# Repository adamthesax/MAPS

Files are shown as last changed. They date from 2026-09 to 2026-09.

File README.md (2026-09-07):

# M.A.P.S. — Modular Awesome Photonic System

**`mapscam`** is the camera-enclosure repository of the M.A.P.S. project: a **modular,
3D-printed enclosure system for board-level C-mount CMOS cameras**, for fixed and monitoring
installations. The housing is a short stack of independent printed modules — front (lens),
body, sensor carrier, rear (cabling) — on one shared mechanical interface, so each piece can
be reprinted or swapped as sensors and lenses change.

Parametric [OpenSCAD](https://openscad.org) source. Mechanical + docs only — no firmware.

> **Status: v0.1 scaffold.** The geometry renders, the flange-focal-distance math is
> enforced in code, and every variant passes `make check`. Nothing has been printed and
> fit-checked against hardware yet — treat dimensions as a starting point, not gospel.

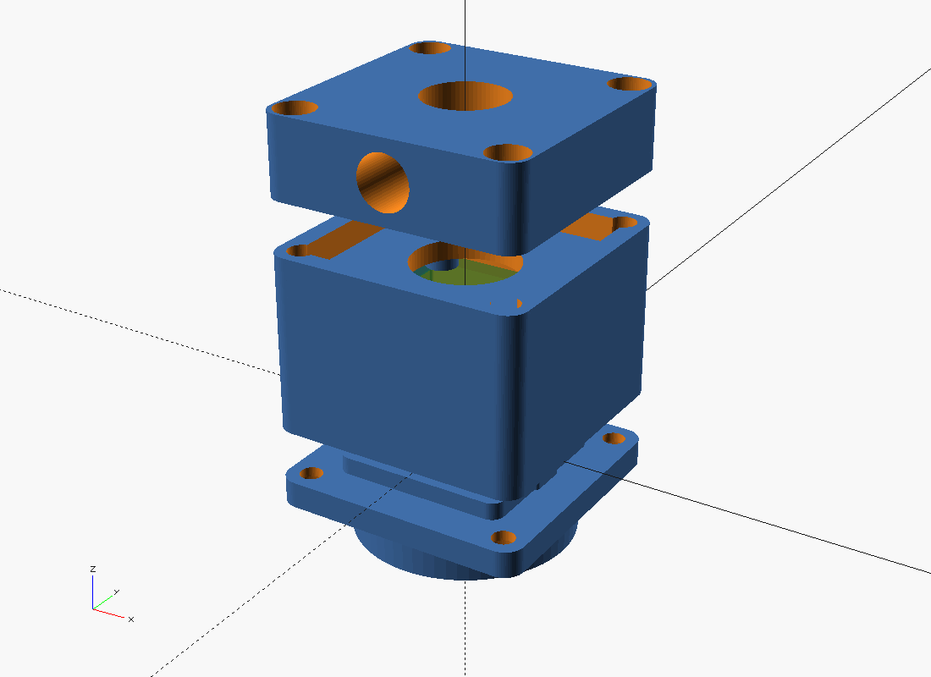
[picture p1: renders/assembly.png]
exploded assembly


## Quick start

```bash
git clone --recurse-submodules <this repo>
cd mapscam
brew install openscad          # or apt / your package manager
python3 --version              # 3.11+ (needed by tools/gen.py — stdlib only)
make check                     # regen check + render every component/part, fail on any warning
make                           # STLs + preview PNGs into stl/ and renders/
```

Render a single part:

```bash
OPENSCADPATH=vendor openscad -o stl/body.stl -D 'part="body"' scad/variants/generic_29mm_c.scad
```

Or open `scad/camera.scad` (or `scad/lens.scad`) in the OpenSCAD GUI and use the
**Customizer**.

## Components

Every buildable thing — a camera enclosure, a printed lens barrel — is one small TOML file
under [`components/`](components/). `tools/gen.py` (run by `make gen`, and automatically by
`make`) expands each into a `scad/variants/<name>.scad` stub plus the Make wiring. **The
TOML is the source of truth**; the `.scad` stubs and `components.json` are generated — do
not hand-edit them. See [docs/components.md](docs/components.md).

<!-- BEGIN GENERATED:components -->
### Camera components

| Variant | Description |
|---|---|
| `generic_29mm_c` | 29 mm board, C-mount, printed thread |
| `generic_29mm_c_ring` | 29 mm board, C-mount, captured metal ring |
| `generic_29mm_cs` | 29 mm board, CS-mount, printed thread |

### Lens components

| Variant | Description |
|---|---|
| `achromat_12mm_c` | Ø12.7 achromat barrel, C-mount, M30.5 filter |

### Receiver components

| Variant | Description |
|---|---|
| `vibrometer_80mm` | Ø80 f150 receiver, fixed focus, 808 nm filter, C-mount |
<!-- END GENERATED:components -->

Add your own: drop a TOML in `components/camera/` or `components/lens/`, run `make gen`,
then `make check`. See [docs/components.md](docs/components.md) and the `add-camera-variant`
/ `add-lens-body` skills.

## The idea in one table

| | C-mount | CS-mount |
|---|---|---|
| Thread | 1.000"-32 UN | 1.000"-32 UN |
| Flange focal distance (flange → sensor) | **17.526 mm** | **12.526 mm** |

`scad/lib/camera/params.scad` does **not** let you set the body length — it *solves* it from
that flange focal distance, your sensor's PCB-to-active-surface number, standoff height, and
a shim allowance, then `assert()`s the stack is physically possible. A printable shim set
(`part = "shims"`) takes up the ± tolerance for back focus.

## Print checklist (per camera)

`front` · `body` · `carrier` · `rear` · `shims` — plus `base` if wall-mounting.
Fasteners, inserts, gland: [docs/bom.md](docs/bom.md).
Material and orientation: [docs/print-settings.md](docs/print-settings.md).

## Repo layout

```
components/            SOURCE OF TRUTH — one TOML per component (+ _type/ defs)
tools/gen.py           expands components/*.toml -> variant stubs + build wiring
scad/
  camera.scad          Customizer entry point (camera type)
  lens.scad            Customizer entry point (lens type)
  lib/
    constants.scad     shared: C/CS optics, thread spec, fastener dims, filter + NATO rail
    util.scad  hardware.scad         shared helpers
    camera/            params · dispatch · interface · front_plate · body ·
                       sensor_carrier · rear_plate · base_mount · accessory_rail ·
                       shims · c_mount
    lens/              params · dispatch · barrel · retainer · hood
  variants/            GENERATED stubs (committed) — do not hand-edit
components.json         GENERATED manifest (committed)
docs/                  components, design notes, modularity, BOM, print, assembly, calibration
vendor/BOSL2/          threading & helpers (git submodule)
```

## Skills

`.claude/skills/` holds repo-specific [Claude Code](https://claude.com/claude-code) skills
for common jobs — adding a camera variant or a lens body, rendering/QC, print prep, tuning
back focus. See [.claude/skills/README.md](.claude/skills/README.md).

## Licence

OpenSCAD sources and tooling: **MIT** ([LICENSE](LICENSE)).
Docs and renders: **CC-BY-4.0** ([LICENSE-docs](LICENSE-docs)).
Vendored BOSL2: BSD-2-Clause (`vendor/BOSL2/LICENSE`).

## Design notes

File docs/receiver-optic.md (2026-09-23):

# Vibrometer receiver optic

A large-aperture receiver telescope for the M.A.P.S. laser vibrometer
(see [PR #1](https://github.com/adamthesax/MAPS/pull/1) for the vibrometer roadmap).
It is its own component **type** (`components/receiver/*.toml`, `scad/lib/receiver/`),
like `lens`, because none of the camera sensor stack applies.

```
  target <--[ Ø80 optic ]===== barrel =====(socket)[ neck + filter cell ][ 1"-32 ]-- camera -- detector
             f ≈ 150 mm    Ø90 tube, holds the optic   plugs in, 3 screws    thread  z = 0   (BPW34 + AFE)
                                                       808 nm filter lives here (all -Z of z=0)
```

The bought **Ø80 mm, f ≈ 150 mm** optic focuses the returned beam through a small
**8 mm 808 nm bandpass filter** onto the detector, which rides on a stock mapscam
camera.

## Camera interface — `mount`

**`mount = "C"` (default).** The `stem` ends in a **male 1"-32 thread** and screws
straight into a stock `generic_29mm_c` front plate (`lens_mount_style = "thread"`) —
the receiver is just a C-mount lens, no custom front plate. A Ø`shoulder_d` disc
gives a finger grip and backstops the thread. **Nothing of the receiver reaches past
the seating plane into the camera** — the bare thread is all that goes +Z, and the
whole filter cell sits at -Z inside the neck root (see below). So the receiver is a
clean C-mount citizen: it drops onto any C-mount camera, and mapscam body variants
can put anything they like right behind the front plate. It seats the same way a
mapscam printed C-mount lens does; the camera shim stack trims focus. A Ø90 barrel
on a printed 1"-32 thread is a long cantilever — plan on a barrel brace for anything
but short bench runs, and a dab of thread-locker or a set screw so it can't back off
under vibration.

**`mount = "flange"`.** The `stem` carries its own front plate — the same
rectangular register + 4-corner M3 pattern as a camera `front_plate` (a bare
`generic_29mm` body bolts straight on). Use this when you want the stiff bolted
joint or a keyed orientation. Set `body_outer_x` / `body_outer_y` to that body's
footprint. Same filter cell, same "nothing into the cavity" rule.

## Fixed focus

This is **one rigid tube**. The `stem` (camera interface + filter cell + a short neck)
plugs `join_len` into a socket in the rear of the `barrel` (holds the optic) and is
pinned with **3 radial screws** into a groove in the neck. `flange_to_optic`
(seating plane → optic rear face) is fixed at the design value; the camera shim stack
takes up the detector-position slack, same as a normal lens.

**Focus control is a later pass** — most likely by making the element position
inside the `barrel` adjustable (a threaded element cell), which is a small, cheap
part and keeps the load path out of any moving joint.

## Ø80 optic cell and lens retainer

The optic **loads from the front (muzzle) end** of the `barrel` and seats on a
shoulder machined into the bore (the step from `pocket_bore` down to `barrel_bore`
at `z = -element_edge_thk`). The `lens_retainer` then **threads into the barrel**
ahead of the optic and clamps it back against that seat — same scheme as the
`lens` component's `scad/lib/lens/retainer.scad`. It is a private printed pair, so it
goes through `print_thread()`: 2.5 mm pitch, 45° flanks, 0.55 mm diametral clearance on
the barrel side, and a 7.5 mm (3-turn) ring. See [printable-threads.md](printable-threads.md),
which uses this thread as its case study.

An earlier revision held the optic with 3 radial M3 set screws into a V-groove on
a plain ring, with the front aperture and the rear (trunk) bore both narrower than
the Ø80 element — the element could not physically pass through either end to
reach its own pocket. The threaded ring fixes this: the whole front bore, from the
muzzle through the retainer thread, stays wider than `element_d` until the seat
shoulder, so the optic drops straight in and only the last step narrows to hold it.

## Coordinate convention

Mirror of the camera: **`z = 0` is the seating plane** (the `"C"` shoulder, or the
`"flange"` front face) that meets the camera. Only the **bare thread** goes **+Z**
(then the camera's own detector); the **filter cell and the optics are all at −Z**,
out toward the target. `stem.scad` is authored in this frame; `barrel.scad` is
authored in its own frame (optic rear face at `z = 0`) and `dispatch.scad` places it
at `−flange_to_optic`.

## The stack (enforced in `scad/lib/receiver/params.scad`)

```
pocket_bore    = element_d + 2·element_fit             // Ø80 optic pocket
barrel_len     = flange_to_optic − stem_neck_len       // optic rear -> barrel rear face
cone_d(z)      = clear_aperture_d · |z| / flange_to_optic   // the light cone behind the optic
neck_bore      = ceil(cone_d(−stem_neck_len − join_len) + 4) // must clear the cone at the joint
neck_od        = neck_bore + 2·wall
socket_bore    = neck_od + 2·join_fit
socket_od      = socket_bore + 2·wall
taper_len      = max(14, (barrel_od − socket_od) / 2)  // OD→socket blend, ≤45° from vertical
```

`taper_len` is set from the radial drop, not fixed, so the barrel's OD→socket cone
is never steeper than 45° from vertical. The barrel prints **optic-end-down**; that
cone's inner face leans in over the main bore as it rises, and ≤45° keeps it
support-free. Bigger optic → bigger drop → longer blend, automatically.

Why the barrel is most of the tube: the f/1.9 cone is still ~Ø45 only 60 mm behind
the optic, so any tube back there has to be wide. The Ø90 barrel bore carries it
until the cone has shrunk to ~Ø18, ~`stem_neck_len` from the flange — that is where
the narrow `stem` neck takes over. Push `stem_neck_len` up and `neck_bore` grows
with it (asserted); push it down and the neck gets stubby.

`assert()`s fail the render if: the clear aperture leaves no seat rim; a wall
(barrel / stem / socket) is under `wall`; the lens retainer thread + wall don't
fit the barrel; the neck bore vignettes the cone at the joint; the filter
retainer thread + wall don't fit the stem neck; the filter cell runs into the
stem↔barrel joint; `thread_bore_d` leaves too little wall on the male thread;
or `flange_to_optic` is too short for the barrel.

## Parts (`make vibrometer_80mm`)

| Part | Prints | Notes |
|---|---|---|
| `stem` | 1 | camera interface (`"C"` male 1"-32 + grip shoulder, or `"flange"` register) + filter cell in the neck root + Ø28 neck. Print shoulder/flange-down; no support. |
| `barrel` | 1 | Ø91 × ~149 mm; optic cell + tube + rear socket, OD→socket blend held to ≤45°. Print optic-end-down, no support, **with a 5–8 mm brim** (the chamfered mouth leaves only a ~2 mm ring on the bed). Big — budget time / filament. |
| `lens_retainer` | 1 | threaded ring: loads from the front (muzzle) end, screws into the barrel's internal thread, and clamps the optic back onto its seat rim (same scheme as `scad/lib/lens/retainer.scad`). |
| `filter_ring` | 1 | top-hat: a Ø8.1 nose drops onto the filter, the Ø17 threaded body engages the stem. Turn from the −Z (barrel) end. |

## 808 nm filter cell

The filter is **Ø8.0 × 0.55 mm glass** (808 nm narrow band-pass, CWL 808 ± 2 nm,
HBW 25 nm, T > 85 %). The whole cell is cut into the **stem neck root, entirely on
the −Z (target/barrel) side of the seating plane** — nothing projects toward the
camera past the bare thread, so any body variant is free to put hardware right
behind the front plate.

Reading −Z from the seating plane (`z = 0`):

```
[ Ø thread_bore_d clear bore, through the thread ]   z = 0 .. thread_engage  (+Z, toward detector)
[ Ø6 field-stop / seat land ]                        z = -0.8 .. 0
[ Ø8.0 filter ]  seats +Z-face-up on the land        z = -1.35 .. -0.8
[ filter_ring Ø8.1 nose ]                            z = -3.35 .. -1.35
[ funnel Ø8.6 -> Ø17 ]                               z = -3.35 .. -1.85
[ Ø17 retainer thread ]  filter_ring body            z = -7.85 .. -3.35
[ ring lead-in -> neck bore Ø22 -> barrel ]          z < -7.85
```

The **`filter_ring`** is a top hat: Ø8.1 nose, Ø17 threaded body, Ø6 through-bore
(the clear aperture). Drop the filter into the pocket from the **−Z (barrel) end**,
then wind the ring in behind it with a long flat screwdriver down the Ø22 neck bore
(turn it before you plug the barrel on). It seats when the **`fring_nose_h` = 2.0 mm
nose meets the filter face at the same instant the ring body shoulder bottoms on the
funnel step** — so the filter is captured with *zero* clamping stress on the thin
glass while the thread carries its full `fring_engage` (4.5 mm = 3 × 1.5 mm pitch) engagement.
That shoulder end of the thread is deliberately left unbevelled: a bevel there would let
the ring run past its stop.

The filter sits ~1 mm target-side of focus. At ~150 mm from a Ø74 aperture the
marginal ray hits it at ≤ 14° — a ~2.5 nm passband shift against a 25 nm half-width,
negligible (the angle is set by aperture ÷ focal length, so the ±few mm of position
doesn't matter).

Fasteners: 3 × M3 (stem↔barrel joint, tapped into the socket wall); the lens
retainer is a threaded ring, no fasteners; `"flange"` only: 4 × M3 into the
body inserts.

## GUESSED numbers — measure and update `components/receiver/vibrometer_80mm.toml`

- `element_edge_thk` — rim thickness of the Ø80 optic (= seat pocket depth).
- `element_sag` — how far the convex face bulges past the rim plane.

The filter is spec'd (Ø8.0 × 0.55 mm). `focal_length` / `flange_to_optic` are set
from the optic spec; if the real optic is not exactly f = 150 mm, set
`flange_to_optic` to its actual back focus.

## Known limitations (v0 — nothing fit-tested)

- **No focus.** Fixed tube — see above. Fine for a fixed bench standoff; add the
  moving-element cell before you need to work multiple target distances.
- **Cantilever.** A Ø90 barrel on a printed 1"-32 thread (`mount = "C"`) or a 39 mm
  flange is floppy held horizontal, and a thread can back off under vibration. Plan
  on a brace around the barrel for anything but short bench runs, and thread-locker
  or a set screw on the C-mount joint. `mount = "flange"` gives the stiffer joint.
- **Filter near the focus.** The 8 mm filter sits ~150 mm from the optic, near
  focus, so marginal rays hit it at up to ~15° — enough to shift a narrow 808 nm
  passband. Fine for qualitative spectra; move it into collimated space if you need
  the full rejection.
- **Stray light.** The stem↔barrel joint is a slip fit, not light-tight; the Ø6
  field stop + the 808 nm bandpass filter are the real defense. Blacken the bores
  and, in sunlight, tape the joint. See `design-notes.md`.
- **Laser path not included** — receiver only, per the current plan. Bistatic
  transmit mount is a separate part.

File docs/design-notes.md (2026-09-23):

# Design notes

## What this is

The camera enclosure of **M.A.P.S. (Modular Awesome Photonic System)** — a modular,
3D-printed enclosure for **bare board-level CMOS camera modules** with a
**C-mount** (or CS-mount) lens interface, intended for **fixed / monitoring** installs.
"Modular" here means the enclosure is a short **stack of independent printed modules** on
one shared mechanical interface:

```
   lens ── [ front_plate ] ── [ body ] ── [ rear_plate ] ── cable
                                 │
                            [ sensor_carrier ]  (holds the PCB, shimmed)
```

Any front pairs with any body pairs with any rear, because they all carry the same
rectangular register + 4-corner M3 pattern (see [modularity.md](modularity.md)).

## The optical constraints that drive every dimension

| Quantity | C-mount | CS-mount | Source |
|---|---|---|---|
| Thread | 1.000"-32 UN | 1.000"-32 UN | `CMOUNT_MAJOR_D`, `CMOUNT_PITCH` in `scad/lib/constants.scad` |
| Flange focal distance (flange face → sensor plane) | **17.526 mm** | **12.526 mm** | `C_MOUNT_FFD`, `CS_MOUNT_FFD` |
| C ↔ CS difference | — | 5.000 mm | printed `spacer` part, or shorter body |

Thread pitch 1"/32 = **0.79375 mm**. That is tight for FDM; the `ring` build exists for
when a printed thread is not accurate or durable enough.

### The stack budget (enforced in code)

`scad/lib/params.scad` derives the body length instead of letting you set it:

```
sensor_z       = FFD                                   // target: sensor surface lands here
pcb_front_z    = sensor_z - board_to_sensor_surface    // datasheet number
pcb_back_z     = pcb_front_z + board_thickness
carrier_face_z = pcb_back_z + standoff_h               // carrier floor
ledge_z        = carrier_face_z - shim_nominal         // body ledge, shimmed
body_length    = carrier_back_z + rear_margin + rear_reg_h - front_mate_z
```

Three `assert()`s fail the render (and `make check`) if the geometry is impossible:
sensor stack landing into the body front face, negative body length, or board mounting
holes falling off the carrier.

Every render also `echo`s the resulting `body_length`, `ledge_z`, and `carrier_face_z` so
you can sanity-check against a caliper.

### Tolerance budget (target, not yet measured on prints)

| Contributor | Budget |
|---|---|
| FFD nominal | 17.526 mm |
| Printed-thread datum vs. model | ± 0.15 mm (see `thread_clearance`) |
| Body length Z (layer height, first-layer squish) | ± 0.15 mm |
| Carrier + standoff Z | ± 0.10 mm |
| **Take-up range needed from shims** | **≈ ± 0.5 mm** |

Hence the printable shim set (`part = "shims"`, values `0.1 / 0.1 / 0.2 / 0.2 / 0.5`) plus
`shim_nominal = 0.6` designed in, so you can *remove* shims as well as add them.
Fine adjustment beyond that = focus ring on the lens.

## Printed thread vs. captured ring

| | `lens_mount_style = "thread"` | `lens_mount_style = "ring"` |
|---|---|---|
| Bought parts | none | one metal C-mount extension/adapter ring |
| FFD repeatability | print-dependent, tune `thread_clearance` | set by the metal part |
| Durability | flanks wear with lens swaps | good |
| Print time | slow (~1 min/part, big STL) | fast |
| Notes | print front plate thread-axis vertical | set `ring_bore_d` to measured OD + ~0.1 mm |

## Lens bodies

`mapscam` also prints **lens barrels** — a holder for bought glass (a singlet, an
achromatic doublet, a salvaged element group) with a male C/CS thread on the back. It is a
separate component *type* (`components/lens/*.toml`, `scad/lib/lens/`), not a camera
variant, because nothing about the sensor stack applies.

Coordinate convention mirrors the camera: **`z = 0` is the flange face** (the shoulder that
seats against the camera front plate), **+Z points toward the front of the lens**, and the
male 1"-32 thread runs `z = -thread_engage … 0` (into the camera).

### The lens stack (enforced in `scad/lib/lens/params.scad`)

```
seat_z       = flange_to_rear_vertex               // rear face of the element group, from z=0
group_thk    = element_count·element_edge_thk + (element_count−1)·element_gap
front_elem_z = seat_z + group_thk
retainer_z0  = front_elem_z                         // coarse printed thread clamps the group back
barrel_front_z = retainer_z0 + retainer_engage + front_rim
total_track  = barrel_front_z + thread_engage
```

`assert()`s fail the render if the rear vertex lands inside the male thread, if
`clear_aperture_d` leaves no seat rim, if the barrel wall is too thin around the retainer
thread, or if a chosen `filter_thread` has no wall over the aperture.

`flange_to_rear_vertex` is the lens equivalent of the camera's `board_to_sensor_surface`:
get it from the element prescription, or measure back focus on the bench and adjust. Fine
focus is still the camera's shim stack plus (for a real lens) the focus ring.

### Limitations

- Fixed focus — no printed helicoid yet. A moving `focus_ring` group is a planned follow-up.
- The retainer thread is a printed `print_thread()` pair (1.5 mm pitch, 45° flanks —
  [printable-threads.md](printable-threads.md)); the optional front
  `filter_thread` is modelled at true 0.5 mm pitch and prints marginally on FDM, same
  caveat as the printed C-mount thread.
- No baffles / internal blackening geometry; paint the bore or add a flock liner.

## Receiver optic (vibrometer)

`mapscam` also prints a **large-aperture receiver telescope** for the M.A.P.S. laser
vibrometer: a bought Ø80 mm f≈150 mm optic, feeding the return beam through an 8 mm
808 nm bandpass filter to a detector on a stock `body`. **Fixed focus for now** — one
rigid tube: a short `stem` (camera interface + filter cell) plugs into the rear of the
long `barrel` (holds the optic) and is pinned with 3 screws. Separate component
*type* (`components/receiver/*.toml`, `scad/lib/receiver/`). By default (`mount = "C"`)
the stem ends in a **male 1"-32 thread** and screws straight into a stock
`generic_29mm_c` front plate — the receiver is just a C-mount lens, no custom plate.
The 808 nm filter cell sits entirely **−Z of the seating plane** in the neck root, so
nothing of the receiver reaches past the front plate into the body — body variants
stay free. `mount = "flange"` keeps the alternative: the stem carries its own
`front_plate`-peer register + M3 pattern and bolts to a bare body. Focus control is a
planned follow-up (a threaded element cell inside the barrel). Full write-up:
[receiver-optic.md](receiver-optic.md).

## Known limitations of v0.1

- Sensor tilt (non-perpendicularity) is controlled only by print flatness of the ledge and
  carrier — no 3-point adjustment yet.
- Tripod boss is on the rear cap edge; not under the centre of mass. The body
  accessory rail (`accessory_rail.scad`, `-Y` by default) is the better load path — a
  NATO clamp on it slides to the balance point. See
  [modularity.md](modularity.md#the-accessory-mount-interface-secondary).
- Accessory-rail profile: the camera "NATO rail" is the Picatinny / STANAG 4694
  clamping geometry run smooth (no recoil grooves) and low. `NATO_*` in
  `constants.scad` use the published **21.2 mm** clamp-chamfer width and 45° flanks so
  off-the-shelf NATO clamps fit; MIL-STD-1913 fixes no height, so it is kept low
  (~5.6 mm). Still test-fit an actual clamp before a production run — jaw depth and
  chamfer land vary between makers. Add the recoil grooves + go to full width if you
  want to use firearms-world clamps instead.
- No gasket groove modelled — sealing is a foam/O-ring pad against flat faces.
- Thermal: no vents or heatsink boss. Fine for low-power global-shutter/rolling sensors
  indoors; revisit for continuous outdoor sun.

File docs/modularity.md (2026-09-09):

# The module interface

Every module mates on a **rectangular register** plus a **4-corner M3 pattern**, both
defined once in `scad/lib/interface.scad`. Get these right and any module you design will
fit the rest.

## The register

| Feature | Value | Where |
|---|---|---|
| Footprint | `outer_x` × `outer_y` = board + `2·inner_clear` + `2·wall` | `params.scad` (computed) |
| Register footprint | `reg_x` × `reg_y` = outer − `2·reg_inset` (`reg_inset = 6`) | `params.scad` |
| Male boss height | `reg_boss_h` = 2.6 mm | `params.scad` |
| Female pocket depth | `reg_pocket_h` = 3.0 mm | `params.scad` |
| Slip fit (radial) | `reg_fit` = 0.15 mm | `params.scad` |
| Index key | 3 × 6 mm tab on **+X**, so a module only assembles one way | `interface.scad` |

`body` has a **female pocket at both ends**. `front_plate` and `rear_plate` each present a
**male boss**. Screws pull the boss into the pocket; the register takes the shear.

## The bolt pattern

`mate_screw_xy()` → four points at `(±(outer_x/2 − 3.5), ±(outer_y/2 − 3.5))`, i.e. the
corners, inside `corner_ears` (Ø7 bosses). `body` holds an **M3 heat-set insert at each of
the 8 positions** (4 front, 4 rear). Front and rear plates have **clearance holes +
cap-head counterbores**. Screw length: front `M3 × 8`, rear `M3 × 12` (rear cap is thicker).

## Z convention

`z = 0` is the **flange face** (lens seating shoulder). **+Z points into the camera**,
toward the sensor and out the back. Every module is authored in these absolute coordinates,
so `dispatch.scad` can just draw them all together for the assembly view.

> The enclosure modules and this interface live in `scad/lib/camera/`. Truly shared
> helpers (`constants.scad`, `util.scad`, `hardware.scad`) stay in `scad/lib/` and are
> included as `../constants.scad` from inside `lib/camera/`.

## The accessory mount interface (secondary)

Separate from the register above. The `body` can carry a **NATO-style dovetail** on
any of its four side faces, full length, defined in
`scad/lib/camera/accessory_rail.scad` (profile constants in `constants.scad`,
`NATO_*`).

| Feature | Value | Notes |
|---|---|---|
| Profile | Picatinny/STANAG-family hex top: 45° chamfers, `NATO_W_MAX`=21.2 across the clamp faces, `NATO_W_TOP`=15.7 flat, ~5.6 proud, smooth | test-fit your clamp first (see design-notes) |
| Faces | `acc_rail_faces`, any of `"-Y"` `"+Y"` `"-X"` `"+X"` (default `["-Y"]`) | −Y is the natural "down"; add faces for a cage-style rig |
| Crown holes | `acc_rail_holes` on/off; row spaced ≤ `acc_rail_pitch` (default 12 mm), anchored at both ends | end holes take clamp stop-screws, interior holes are adapter bolt points |
| Ends | both open, no dam | clamp held by jaw friction + a stop screw in an end crown hole |

Two ways to hang something off a rail:

1. **NATO clamp** (bought or printed) grips the 45° flanks — slides along the rail,
   so you park it at the balance point for whatever lens is fitted. This is the
   answer to "the tripod boss isn't under the centre of mass".
2. **Bolt-on adapter** — screws to the crown M3s. Give the adapter a stub dovetail
   foot too, so the flanks take shear + anti-rotation and the M3 is just retention;
   the same adapter then works clamped or bolted. Keep bolt-on loads light (cold
   shoe, bracket, antenna); a camera + lens on a tripod should go through a clamp.

Params live in `params.scad`. `acc_rail` is the master switch; the rail geometry
takes `body_length` from the body it sits on, so it always spans the full module
regardless of variant. `-D acc_rail=false` for a build without any.

## Adding a new module

1. `include <params.scad>; use <interface.scad>; use <../util.scad>;` (in `scad/lib/camera/`)
2. Build your solid in absolute Z. Union `corner_ears(h)` and either `reg_boss()` (if you
   mate to a body pocket) or cut `reg_pocket()` (if a boss mates into you).
3. Cut fasteners with `mate_screws("clear", h)` or `mate_screws("insert-…")`.
4. Add a `part == "yourthing"` branch in `scad/lib/camera/dispatch.scad`, and add the part
   name to `parts` / `check_parts` in `components/_type/camera.toml`.
5. `make gen && make check` — the asserts and `--hardwarnings` must stay green.

## Adding a new variant

Variants are config-driven. Drop a TOML in `components/camera/` with the overrides (board
size, hole pitch, mount type/style, gland), run `make gen`, then `make <name>`. The
`scad/variants/*.scad` stubs and the `Makefile` lists are generated — see
[components.md](components.md).

## Parameter override mechanics (important)

`params.scad` uses **plain assignments** so the OpenSCAD Customizer works. A generated
variant stub does `include <../lib/camera/params.scad>` **first**, then re-assigns the few
parameters the TOML pins, then `include <../lib/camera/dispatch.scad>`.

That re-assignment alone does **not** reach the geometry. `dispatch.scad` pulls the part
modules with `use <body.scad>` etc., and OpenSCAD resolves a `use`d module's free
variables (`body_length`, `outer_x`, `mount_type`, the whole derived stack…) against **its
own definition scope** — i.e. the *defaults* from that part file's own
`include <params.scad>` — not the stub's scope. A `-D name=value` on the command line is
applied globally and *does* reach `use`d modules.

So the real path: `tools/gen.py` emits each variant's TOML overrides as `-D` flags
(`DFLAGS_<name>` in `build/components.mk`) and the `Makefile` passes them on **every**
`openscad` call — STL, preview PNG, and the `make check` loop. Any `openscad` you run by
hand on a stub needs the same flags (`grep DFLAGS_<name> build/components.mk`), or just run
it on `scad/camera.scad` with your own `-D`.

The stub's in-file assignments keep it a valid Customizer target and feed `params.scad`'s
own `echo`/`assert`s, but a live Customizer edit hits the same `use <>` scope wall — a
fully faithful interactive Customizer would need the part files to stop self-including
`params.scad` (left as future work). `make check` has a `check-overrides` guard that fails
if the C and CS `body` render to the same length — which is exactly what happens if the
`-D` flags stop being applied.

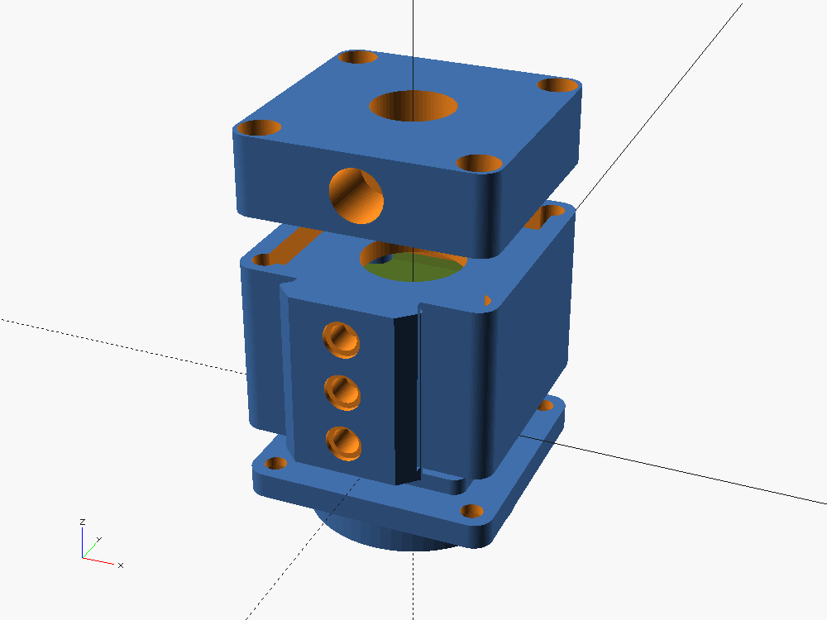
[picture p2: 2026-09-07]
renders/generic_29mm_c_ring.png

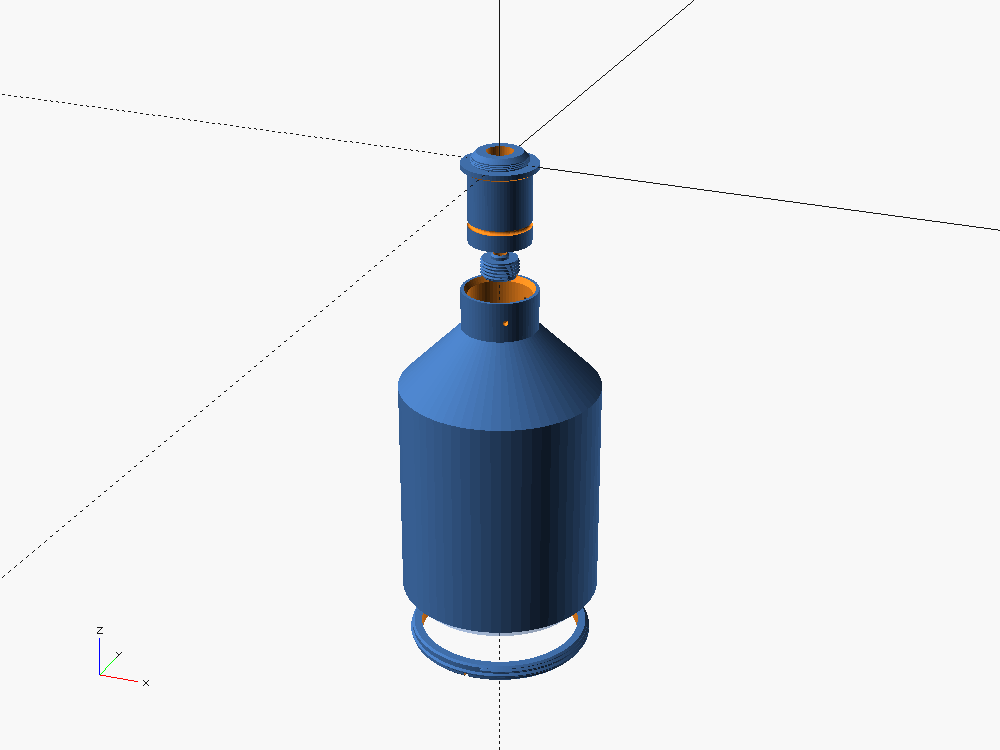
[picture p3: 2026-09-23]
renders/vibrometer_80mm.png

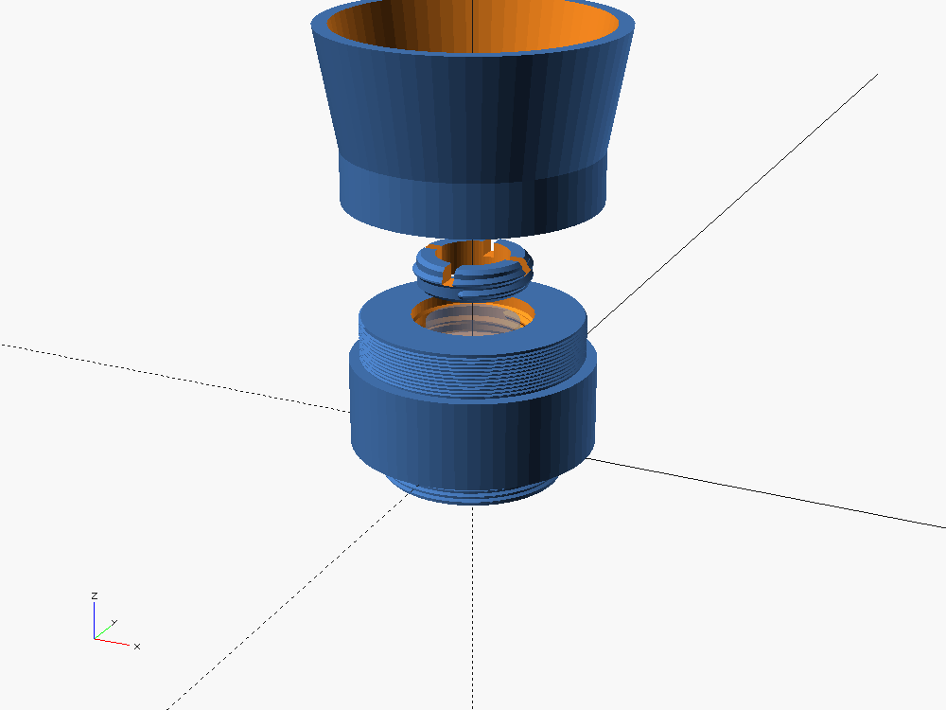
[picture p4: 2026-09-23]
renders/achromat_12mm_c.png

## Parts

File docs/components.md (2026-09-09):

# Components & the config system

Every buildable thing in `mapscam` — a camera enclosure, a printed lens barrel — is one
small **TOML file** under `components/`. `tools/gen.py` expands each into an OpenSCAD stub
and the build wiring. **The TOML is the single source of truth.**

```
components/
  _type/
    camera.toml            # type definition (hand-edited)
    lens.toml
  camera/
    generic_29mm_c.toml    # one component  (hand-edited)
    ...
  lens/
    achromat_12mm_c.toml
```

## Generated files — never hand-edit

| File | Committed? | What |
|---|---|---|
| `scad/variants/<name>.scad` | yes | `include params` → re-assign → `include dispatch` stub — the Customizer target (the `make` render path also passes `DFLAGS_<name>`, see modularity.md) |
| `components.json` | yes | flat manifest of every type + component |
| `build/components.mk` | no (git-ignored) | `ALL_VARIANTS`, `PARTS_<name>`, `PREVIEW_CAM_<name>`, `CHECK_JOBS`, `DFLAGS_<name>` (the TOML overrides as `-D` flags), … included by the `Makefile` |
| `README.md` (between `<!-- … GENERATED:components … -->`) | yes | the component tables |

Run `make gen` after editing any TOML. `make` and `make check` run it automatically;
`make check` also runs `python3 tools/gen.py --check`, which fails if a committed generated
file is stale (so CI catches a forgotten `make gen`).

## Component type — `components/_type/<type>.toml`

```toml
lib         = "scad/lib/camera"                   # module dir for this type
entry       = "scad/camera.scad"                  # Customizer entry for the type
params_file = "scad/lib/camera/params.scad"       # generator validates [params] keys against this
parts       = ["front", "body", "carrier", "rear", "base", "shims"]
check_parts = ["front", "body", "carrier", "rear", "base", "shims", "assembly"]
preview_cam = "0,0,18,62,0,23,235"                # --camera=<…> for the preview PNG
```

A type's SCAD side is a `lib/<type>/` directory with `params.scad` (plain assignments +
Customizer annotations + a derived section + `assert()`s) and `dispatch.scad` (a
`part == "…"` selector plus an `assembly` preview), fronted by `scad/<type>.scad`.

## Component — `components/<type>/<name>.toml`

```toml
type  = "camera"
title = "29 mm board, C-mount, printed thread"

[params]                     # keys map 1:1 to params.scad variables (and to -D overrides)
mount_type         = "C"
board_x            = 29
board_hole_pitch_x = 22
```

- `name` is the filename stem; it must be unique across all types.
- List only parameters that **differ** from the type's `params.scad` defaults.
- Values become SCAD literals: string → `"…"`, bool → `true`/`false`, number verbatim,
  array → `[a, b, c]`.
- An unknown key, or a file in the wrong `type/` directory, fails `make gen`.

## Add a component

1. `components/<type>/<slug>.toml` — `type`, `title`, `[params]`.
2. `make gen` — writes `scad/variants/<slug>.scad` and the wiring.
3. `make check` — asserts + `--hardwarnings` for every part.
4. `make <slug>` — `stl/<slug>-*.stl` + `renders/<slug>.png`. Read the PNG and the echoed
   stack numbers.

Removing a TOML and re-running `make gen` deletes its orphaned stub.

## Add a component type

1. `scad/lib/<type>/params.scad`, `dispatch.scad`, and the module files. Shared helpers stay
   in `scad/lib/` (`constants.scad`, `util.scad`, `hardware.scad`) and are included as
   `../constants.scad` from inside `lib/<type>/`.
2. `scad/<type>.scad` — `include <lib/<type>/params.scad>; include <lib/<type>/dispatch.scad>;`
3. `components/_type/<type>.toml` — see above.
4. `components/<type>/*.toml`, then `make gen && make check`.

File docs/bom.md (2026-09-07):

# Bill of materials

Per camera, `generic_29mm_c` baseline. Quantities scale with your board.

## Printed parts

| Part | Qty | `part=` | Notes |
|---|---|---|---|
| Front plate | 1 | `front` | thread-axis vertical on the bed |
| Body | 1 | `body` | length is variant-dependent |
| Sensor carrier | 1 | `carrier` | standoffs up |
| Rear cap | 1 | `rear` | |
| Shim set | 1 sheet | `shims` | 0.1 / 0.1 / 0.2 / 0.2 / 0.5 mm |
| Wall bracket | 0–1 | `base` | optional, for wall/ceiling mounts |
| C↔CS spacer | 0–1 | `spacer` | only if mixing C body with CS lens |

## Fasteners & inserts

| Item | Qty | Spec |
|---|---|---|
| Heat-set insert, M3 × L5 (OD ≈ 4.0) | 8 + ~3/rail | body: 4 front + 4 rear; +~3 per accessory rail (if `acc_rail_holes`) |
| Heat-set insert, M2 × L4 (OD ≈ 3.2) | 4 | carrier standoffs (PCB screws) |
| Heat-set insert, 1/4"-20 (OD ≈ 8.0, L10) | 1–2 | rear cap edge (tripod); +1 in the `base` boss if wall-mounting |
| Cap screw, M3 × 8 | 4 | front plate → body |
| Cap screw, M3 × 12 | 4 | rear cap → body |
| Screw, M2 × (6–8, per standoff+PCB) | 4 | PCB → carrier |
| Grub screw, M2 × 3 | 3 | **`ring` build only** — retains the metal ring |

## Bought hardware

| Item | Qty | Notes |
|---|---|---|
| Metal C-mount ring / adapter | 1 | **`ring` build only.** Measure OD, set `ring_bore_d`. |
| Cable gland, PG7 (or PG9/PG11) | 1 | matches `gland`; PG7 hole = 12.5 mm |
| Foam or O-ring gasket stock | ~0.3 m | between register faces if you need light/dust sealing |
| Silica gel pack, ~1 g | 1 | fits the rear-cap desiccant pocket |
| C-mount lens | 1 | image circle must cover your sensor diagonal |
| NATO clamp (bought or printed) | 0–1 | grips the body −Y accessory rail; carries your 1/4"-20 / arm / arca plate |
| Screw for accessory-rail stop | 1–2 | M3 button head in the end crown holes, backs out the clamp travel |

## Consumables

- PETG or ASA filament, ~60 g per camera (see [print-settings.md](print-settings.md)).

---

## Lens barrel (`components/lens/*`)

A separate component type — a printed holder for bought glass. Parts: `barrel`, `retainer`,
`hood`.

| Item | Qty | Notes |
|---|---|---|
| Lens element / achromatic doublet | 1 group | Ø set by `element_d`; measure the edge thickness → `element_edge_thk` |
| Printed retainer ring | 1 | `part=retainer`, coarse printed thread, clamps the group back against the seat |
| Printed hood | 0–1 | `part=hood`, threads onto the filter thread or slips over the barrel OD |
| Black paint / flock liner | a little | kill internal reflections in the bore |

No fasteners. Set `flange_to_rear_vertex` from the lens prescription or bench back-focus;
fine focus is the camera's shim stack. `spacer` (C↔CS 5 mm ring) stays a camera part.

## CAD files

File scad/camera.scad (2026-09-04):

// mapscam — top-level entry point and OpenSCAD Customizer target.
//
// Render one part, or the whole assembly, by setting `part`
// (edit params.scad, use the Customizer, or pass -D on the command line):
//
//   OPENSCADPATH=vendor openscad -o stl/body.stl -D 'part="body"' scad/camera.scad
//
// Parts: assembly | front | body | carrier | rear | base | shims | spacer
//
// For a whole named build (specific board size, mount type, ...) see
// scad/variants/*.scad and `make`.

include <lib/camera/params.scad>
include <lib/camera/dispatch.scad>

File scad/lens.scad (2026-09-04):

// mapscam — printed lens barrel entry point and OpenSCAD Customizer target.
//
// Render one part, or the exploded assembly, by setting `part`
// (edit lib/lens/params.scad, use the Customizer, or pass -D on the command line):
//
//   OPENSCADPATH=vendor openscad -o stl/barrel.stl -D 'part="barrel"' scad/lens.scad
//
// Parts: assembly | barrel | retainer | hood
//
// For a whole named build (element dimensions, filter thread, ...) see
// components/lens/*.toml + scad/variants/*.scad and `make`.

include <lib/lens/params.scad>
include <lib/lens/dispatch.scad>

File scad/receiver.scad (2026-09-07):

// mapscam — vibrometer receiver optic: entry point and OpenSCAD Customizer target.
//
// A large-aperture receiver telescope for the M.A.P.S. laser vibrometer: a bought
// Ø80 mm f≈150 mm optic in a fixed-length tube, feeding the returned beam through
// an 808 nm bandpass filter to a detector on a stock mapscam camera.
//
//   OPENSCADPATH=vendor openscad -o stl/barrel.stl -D 'part="barrel"' scad/receiver.scad
//
// Parts: assembly | stem | barrel | lens_retainer | filter_ring
// Fixed focus for now: `stem` (camera interface + filter) plugs into the rear of
// `barrel` (holds the optic) and is pinned with 3 screws. By default `stem` ends in
// a male 1"-32 thread and screws into a stock generic_29mm_c front plate
// (mount = "C"); mount = "flange" gives it a bolt-on front plate instead.
//
// For a whole named build (element size, focus range, filter) see
// components/receiver/*.toml + scad/variants/*.scad and `make`.

include <lib/receiver/params.scad>
include <lib/receiver/dispatch.scad>

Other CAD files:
scad/variants/achromat_12mm_c.scad
scad/variants/generic_29mm_c.scad
scad/variants/generic_29mm_c_ring.scad
scad/variants/generic_29mm_cs.scad
scad/variants/vibrometer_80mm.scad

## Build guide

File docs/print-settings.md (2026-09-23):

# Print settings

## Material

| Choice | Why |
|---|---|
| **PETG** (default) | dimensionally stable, low warp, tolerates the warmth near a sensor, cheap |
| **ASA / ABS** | outdoor / UV exposure, higher temp; needs an enclosure to print |
| PLA | prototyping only — creeps under fastener preload and sags if the camera warms |

## Slicer profile

| Setting | Value | Reason |
|---|---|---|
| Layer height | 0.16 mm | Z resolution feeds straight into flange-focal-distance error |
| First layer | 0.20 mm, slow | flat, square datum faces |
| Perimeters / walls | 4 | strong threads, solid insert bosses |
| Top / bottom layers | 5 / 5 | opaque, light-tight |
| Infill | 30–40 % gyroid | |
| Supports | **none by design** — see orientation below | |
| Seam position | rear / aligned, away from the register and thread | |
| Horizontal expansion / XY compensation | tune so an M3 heat-set pocket measures Ø4.0 | |

## Orientation

| Part | Orientation | Note |
|---|---|---|
| `front` | **thread axis vertical**, lens tower up | clean thread, no bridging over the bore |
| `body` | open end up (either end) | register pockets bridge fine at ≤ 3 mm; add a 0.3 mm ledge chamfer if sagging. Accessory rail runs vertical in this pose → dovetail prints clean, no supports |
| `carrier` | floor down, standoffs up | |
| `rear` | outside face down | gland hole bridges; fine |
| `shims` | flat | print one sheet; they're fragile — handle with tweezers |
| `base` | plate flat on the bed, boss + countersinks up | boss prints unsupported; the pocket floor bridges its Ø4 vent fine |

Threads: see [printable-threads.md](printable-threads.md). Print every threaded part
**thread axis vertical**. That covers the receiver `barrel` optic-end-down, its
`lens_retainer` flat with the clamp face on the bed, and the `filter_ring` standing on
its nose.

## Post-processing

1. Install heat-set inserts with a soldering iron + insert tip. Press square. Let cool
   before loading.
2. Run a tap / the actual lens through printed threads to clear strings.
3. Test-fit the register (front boss into body pocket) — it should be a firm hand push.
   Too tight: raise `reg_fit`. Too loose: lower it, reprint.

## Dimensional QC before assembly

- Caliper the body length; compare to the `body_length` value `echo`ed at render time.
- Thread ring gauge or the real lens: it should seat without cross-threading.
- Carrier + PCB dry stack height vs. `carrier_face_z − pcb_front_z`.

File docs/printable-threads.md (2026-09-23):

# Printable threads

Rules for every thread in `mapscam`. Most of them are enforced by code:
`print_thread()` in [`scad/lib/threads.scad`](../scad/lib/threads.scad) asserts the
numbers, and `make check-threads` (part of `make check`) fails the build on any printed
thread that bypasses the helper. The numbers live in `scad/lib/constants.scad` (`PT_*`).
They are tuned for a 0.4 mm nozzle at the 0.16 mm layers in
[print-settings.md](print-settings.md).

## Two kinds of thread

| Kind | Example | What to do |
|---|---|---|
| **Private printed pair**: both halves are printed, and nothing bought has to fit | receiver `lens_retainer` ↔ `barrel`, `filter_ring` ↔ `stem`, lens `retainer` ↔ `barrel` | `print_thread()` only. Profile, pitch, clearance and length are all yours to choose, so choose printable ones. |
| **Interchange**: has to mate a bought metal part | 1"-32 C-mount, Mxx×0.5 filter threads | Keep the standard ISO/UN profile. Call BOSL2 `threaded_rod()` directly with `// interchange: <standard>` in the 3 lines above it. Expect a marginal print (see [Interchange threads](#interchange-threads)). |

If you are not sure which kind a thread is, it is private.

## The rules

1. **Print with the thread axis vertical.** Each turn then goes down as a nearly flat
   ring, one layer on the next, with no supports. With the axis horizontal, the bottom
   of every turn is an unsupported overhang and the thread goes oval. If you really
   can't avoid it, BOSL2's `teardrop=` is the fallback, and the part will fit worse.
2. **Pitch ≥ 1.5 mm, and 2–2.5 mm is better** (`PT_MIN_PITCH`). A 0.4 mm nozzle lays a
   line about 0.45 mm wide. At 1 mm pitch or finer, each flank is only one or two lines
   and neighbouring turns merge. That leaves at least 9 layers per pitch at 0.16 mm.
   Larger diameters should use a coarser pitch: it is more forgiving of out-of-round.
3. **Always give clearance, and put it on the internal part.** Diametral
   clearance = `0.30 + 0.003·d` mm (`print_thread_clearance(d)`), so 0.35 at Ø17 and
   0.55 at Ø85. It grows with d because shrinkage and out-of-round both scale with the
   size of the circle. BOSL2's `$slop` defaults to **0**, so a raw `threaded_rod(internal=true)`
   at the same `d` as its male half gives a zero-clearance pair that will not assemble.
   Both halves take the same nominal `d`, and the internal cutter adds the clearance.
4. **Use 45° flanks, not 60°.** An ISO/UN 60° thread has flanks only 30° above
   horizontal, so printed axis-vertical every turn has a 60° overhang: droopy undersides
   and ragged roots. `print_thread()` cuts a 90° included-angle trapezoid instead. Its
   flanks sit at 45°, the steepest overhang FDM prints cleanly. It has flat crests and
   roots (0.15·P each) instead of knife edges, and a depth of 0.35·P (`PT_DEPTH_RATIO`).
5. **Thread length ≥ 3 pitches** (`PT_MIN_TURNS`). Blunt starts (rule 6) trim about half
   a turn at each end, which leaves about 2 working turns. That is plenty for a
   retaining ring clamping glass. Anything carrying real preload should use more turns,
   or a heat-set insert.
6. **Blunt starts, plus a bevel at both ends.** `print_thread()` always uses
   `blunt_start`, so there is no feather-edge partial turn left to cross-thread. It also
   bevels each end by one thread depth at 45°. The bevel gives a lead-in, and on the bed
   face it absorbs elephant's foot, the squashed first layer that otherwise binds the
   first turn. An internal thread whose mouth is on the bed gets its own 45° mouth
   flare too (see the receiver barrel).
   - **Exception:** never bevel an end that is a *depth stop*. Turn it off with
     `bevel1/bevel2 = false`. Example: the `filter_ring` shoulder lands exactly when its
     nose meets the filter. A bevel there would let it run on and load the glass.
7. **Fine facets.** `print_thread()` uses `$fa = 1, $fs = 0.4` (`PT_FA`, `PT_FS`), so chords
   are at most 0.4 mm. A coarse `$fn` on a big thread gives flat facets whose sag eats the
   clearance: `$fn = 64` at Ø85 means 4.2 mm chords.
8. **Size walls from the cut, not the nominal.** The wall behind an internal thread is
   measured from `print_thread_bore(d)` (nominal + clearance). The male's minor diameter,
   `print_thread_minor(d, pitch)`, is what has to clear any bore inside it. Write the
   `params.scad` asserts against those two, not against `d`.
9. **Minimum diameter: 8 mm** (`PT_MIN_D`). Smaller printed threads are only a few
   nozzle widths tall. Use a brass heat-set insert (`constants.scad`) instead.

## Slicer

On top of [print-settings.md](print-settings.md):
- 4 perimeters. The thread is all perimeter, and infill never reaches it.
- Slow outer wall for the threaded part. Put the seam **aligned / rear**, not random: a
  random seam puts a zit on every turn.
- Leave XY / hole compensation at the value tuned for the M3 insert pocket. Don't add
  extra compensation to "fix" a thread. Change `PT_CLEAR_BASE` instead, so the model
  stays the truth.
- Print both halves of a pair on the same printer in the same material. PETG shrinks
  about 0.3–0.5 %, which is ~0.3 mm on Ø85, and the clearance assumes both halves shrink
  alike.

## Tuning

Clearance is set by printer and material, and there are two knobs:
- **Every thread too tight or too loose:** change `PT_CLEAR_BASE` in `constants.scad`.
  Re-render both halves.
- **Only one thread is off:** pass `clearance =` to that `print_thread()` call (the
  internal half) and note why in a comment.

Before reprinting a big part, print a short test ring. Set `print_thread(l = 3·pitch)` on
a thin tube for both halves (minutes of printing, versus hours for the receiver barrel).

## Interchange threads

These have to take a bought metal part, so they keep the standard profile and pitch.
They are knowingly marginal on FDM:

| Thread | Pitch | Layers / pitch @ 0.16 | Advice |
|---|---|---|---|
| 1"-32 UN C-mount | 0.794 mm | 5 | Fine for prototypes. For anything you'll keep, use the captured metal ring build (`lens_mount_style = "ring"`, `docs/design-notes.md`). Chase with the actual lens. |
| Mxx×0.5 filter | 0.5 mm | 3 | Expect to chase it with the filter. Use a bought step ring if it matters. |

A raw BOSL2 call is still better with `bevel=true` at the lead-in end and a real
`thread_clearance`. Neither is automatic outside `print_thread()`.

## Case study: the vibrometer receiver retainer

The Ø84.6 thread that clamps the Ø80 optic printed badly. Everything that was wrong
with it is a rule above:

| Was | Rule | Now |
|---|---|---|
| male and female both at `d = 84.6`, `$slop = 0`, so **zero clearance** | 3 | internal cut at Ø85.15 (0.55 diametral) |
| 60° ISO profile, 2.0 mm pitch: 60° flank overhangs | 4, 2 | 45° flanks, 2.5 mm pitch, 0.875 mm deep, flat crests |
| `$fn = 64` at Ø85, 4.2 mm facets | 7 | ≤ 0.4 mm chords |
| no bevel on the ring's bed face, square mouth on the barrel's bed face | 6 | 45° bevel on both, plus a mouth flare |
| 6 mm ring = 3 turns, minus the blunt starts | 5 | 7.5 mm ring (3 × 2.5); the barrel cell is 1.5 mm longer |

The filter ring (Ø17 × 1.5) and the `lens` component's retainer (1.0 → 1.5 mm pitch)
moved onto `print_thread()` in the same change.

## Sources

- [Meshra — How to design 3D printed threads](https://meshra.ai/blog/design-3d-printed-threads):
  pitch vs nozzle, clearance ranges, trapezoidal over 60° V, axis-vertical orientation.
- [Snapmaker — Guide to designing and 3D printing threads](https://www.snapmaker.com/blog/3d-printing-threads/):
  45° lead-in chamfers on the screw and the nut mouth, trapezoidal profile, axis
  vertical, and clearance by offsetting one half (they shrink the male; we grow the
  female, which works the same way and keeps the male at its nominal size).
- [BOSL2 `threading.scad`](https://github.com/BelfrySCAD/BOSL2/wiki/threading.scad):
  `$slop` adds `4·$slop` to internal threads and is 0 by default. `blunt_start` is
  recommended for printing. The example "a 90° thread, resulting in 45° slopes friendly
  for 3D printing". The default blunt-start bevel is r/6, which is why `print_thread()`
  sizes its own.
- [JLC3DP — Considerations for 3D printing threads](https://jlc3dp.com/blog/considerations-for-3d-printing-threads):
  layer height as a fraction of pitch.
- [CNC Kitchen — M3–M10 printed thread test](https://www.printables.com/model/81211-m3-m10-3d-printed-thread-test):
  small printed threads are weak, so use inserts below ~M8.

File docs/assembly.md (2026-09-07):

# Assembly

Tools: soldering iron with heat-set tip, 1.5/2 mm hex drivers, tweezers, calipers.

## 1. Inserts

- Body: 8 × M3 inserts (4 each end), flush and square.
- Body accessory rail: ~3 × M3 inserts per rail crown (only if `acc_rail_holes`), flush
  or a hair below — a proud insert fouls a NATO clamp.
- Carrier: 4 × M2 inserts in the standoff tops.
- Rear cap: 1 × 1/4"-20 insert in the edge boss.
- Wall bracket (optional): 1 × 1/4"-20 insert in the central boss, pressed in from the
  boss (top) side; the Ø4 hole behind it is a vent, not a through-clearance.

## 2. Sensor carrier

1. Sit the bare PCB on the carrier standoffs, sensor facing **out** (toward the lens).
2. Screw down with M2 screws. Snug, not crushing — the PCB should sit flat with no rock.
3. Route the cable out through the carrier's rear relief notch.

## 3. Set the stack into the body

1. Drop the **nominal shim stack** (≈ `shim_nominal`, e.g. 0.2 + 0.2 + 0.2) onto the body
   ledge.
2. Lower the carrier in, front face down onto the shims. It is captured laterally by the
   cavity walls.

## 4. Front plate

1. **`thread` build:** nothing to add — the lens threads straight into the printed front.
   **`ring` build:** press/seat the metal C-mount ring into the front-plate pocket, lock
   with the 3 grub screws.
2. Mate the front-plate boss into the body's **front** pocket. The index key (+X) only lets
   it go one way.
3. 4 × M3 × 8 through the front into the body inserts. Cross-tighten gently.

## 5. Rear cap

1. Fit the cable gland to the rear cap; feed the cable through.
2. Drop a silica-gel pack into the desiccant pocket.
3. Mate the rear boss into the body's **rear** pocket, 4 × M3 × 12, cross-tighten.

## 6. Lens & focus

Thread the C-mount lens in. Then follow [calibration.md](calibration.md) to set back focus
(shim stack) and lock the lens focus ring.

## 7. Mount

- Accessory rail (−Y by default; any side via `acc_rail_faces`): slide a NATO clamp onto
  the rail and thread an M3 stop screw into an end crown hole so it can't slide off. Park
  the clamp at the balance point for your lens. The clamp carries whatever you want —
  1/4"-20, arca plate, arm. Or bolt a light adapter straight to the crown M3s.
- Tripod / CCTV arm: 1/4"-20 in the rear-cap edge.
- Wall / ceiling: print `base`, heat-set a 1/4"-20 insert in its boss, screw the plate flat
  to the surface (screw heads countersink into the boss face), then thread a 1/4"-20 stud
  into the insert and the camera's rear-cap 1/4"-20 onto the stud.

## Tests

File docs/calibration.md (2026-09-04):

# Back-focus calibration

Goal: the sensor plane sits exactly one flange-focal-distance behind the lens flange, so the
lens reaches **infinity focus** with its focus ring near — not jammed against — its infinity
stop, and its full focus range is usable.

## Symptoms

| What you see | Likely cause | Fix |
|---|---|---|
| Can't reach sharp focus on a distant target; ring hits the infinity stop first | sensor too **far** from flange (FFD too long) | **remove** shims |
| Distant target sharp only with the ring well **past** infinity | sensor too **close** (FFD too short) | **add** shims |
| Sharp in the centre, soft at edges, tilts across frame | sensor not perpendicular | reprint ledge/carrier flat; check PCB seating |
| Never sharp anywhere | wrong lens image circle, or debris on sensor | — |

## Procedure

1. Aim at a **high-contrast target ≥ 50 × focal length away** (outdoors, or a detailed wall
   across a room). Open the aperture fully (worst-case depth of field — most sensitive).
2. Set the lens focus ring **to its infinity mark** and lock nothing yet.
3. Look at a live view at 100 %. If it is not sharp:
   - Sharpest with ring **before** infinity → remove ~0.2 mm of shim.
   - Can't get there, ring at the stop → add ~0.2 mm of shim.
4. Reassemble, repeat. Converge to within one 0.1 mm shim.
5. Fine-trim with the focus ring, then **lock the ring** (grub screw or paint).
6. Record the final shim stack in your build log / the variant's notes.

## If you run out of shim range

- Check the `echo`ed `carrier_face_z` against a caliper measurement of the printed carrier
  + standoffs. A consistent offset means a print-scale or `board_to_sensor_surface` error —
  correct the parameter and reprint the body rather than stacking shims.
- The `board_to_sensor_surface` value is the usual culprit: it is the distance from the PCB
  front face to the **sensor active surface** (top of the cover glass / die), from the
  sensor datasheet — not the PCB-to-connector height.

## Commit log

2026-09-04 Initial commit: M.A.P.S. camera enclosure scaffold
    Parametric OpenSCAD source for the modular 3D-printed C-mount camera
    enclosure: library modules, three generic 29mm variants, build tooling,
    docs, and repo skills. v0.1 scaffold — math and renders check out,
    nothing fit-tested against hardware yet.
    [camera.scad, generic_29mm_c.scad, generic_29mm_c_ring.scad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]
2026-09-04 Config-driven components (TOML) + a lens component type
    A camera variant used to be defined in four places that drift: the
    scad/variants/*.scad override list, variants.json ("documentation, not
    source of truth"), the Makefile VARIANTS/PARTS lists, and the README
    table. Nothing machine-read variants.json.
    Now every buildable thing is one TOML file under components/, and
    tools/gen.py (stdlib only, Python 3.11+) expands it into:
    - scad/variants/<name>.scad stubs (committed, generated header)
    - components.json (committed manifest, replaces variants.json)
    - build/components.mk (git-ignored, drives the Makefile)
    - the README component tables (between GENERATED markers)
    gen.py validates e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
    [achromat_12mm_c.scad, camera.scad, generic_29mm_c.scad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]
2026-09-04 Add receiver optic component type + Ø80 f150 vibrometer receiver
    New component type `receiver` (components/receiver/*.toml, scad/lib/receiver/)
    for the M.A.P.S. laser vibrometer (PR #1): a large-aperture receiver telescope
    that focuses the return beam through an 8 mm 808 nm bandpass filter onto a
    detector on a stock mapscam body.
    - draw-tube focuser: wide `barrel` (holds the Ø80 optic) telescopes over the
    narrow `stem` (fixed to the flange); a split-clamp collar with one M3 pinch
    screw locks focus. Default travel 125-175 mm about a 150 mm nominal.
    - `stem` presents the shared rectangular register + 4-corner M3 pattern (verbatim
    from camera/interface.scad) so it bolts onto a generic_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
    [receiver.scad, vibrometer_80mm.scad]
2026-09-04 receiver: wrap-around split clamp collar instead of integral pinch lugs
    The barrel's rear collar is now a 3-slot collet; a separate `clamp` ring wraps
    it and one tangential M4 pinch screw squeezes the collet onto the stem. The ring
    also covers the collet slots, so it doubles as a light seal on the split (the
    old integral +X pinch lug left the slot open to ambient).
    - new part `clamp` (scad/lib/receiver/clamp.scad); parts list + echo updated
    - barrel.scad: drop the lug/block, collet OD now derived as `collar_od` in
    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
2026-09-04 receiver: add fine-focus helicoid (flange/stem split)
    Second focus stage on top of the coarse draw-tube + wrap clamp:
    - `stem` splits off `flange`. The flange grows a male square-thread boss; the
    stem's top is a knurled female-helicoid collar that threads onto it. Rotate the
    stem ~2.4 turns for fine_travel = 6 mm continuous; a radial M3 grub in the collar
    locks it. Moves the whole optical tube against the body-mounted detector
    (camera-lens-style focus); nothing a cable crosses rotates.
    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
    [receiver.scad, vibrometer_80mm.scad]
2026-09-06 receiver: regen vibrometer_80mm preview from the declared preview_cam
    The committed PNG was rendered at an ad-hoc camera; regenerate it via
    `make vibrometer_80mm` so it matches PREVIEW_CAM in components/_type/receiver.toml
    (and what CI produces).
2026-09-06 receiver: firm up the fine-focus helicoid
    The helicoid was modelled too coarsely (~5 extrude slices/turn) — it rendered as a
    ragged spiral fin and would have engaged badly.
    - helix.scad: ~22 slices/turn (was ~5), HELIX_FN 30 -> 60. The thread is now a
    clean Ø36 / 2.5 mm-pitch / 1.5 mm-deep square thread — coarse but solid, prints
    vertical with no support.
    - helix_engage 8 -> 10 mm (4 turns always meshed, was ~3).
    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
2026-09-06 receiver: drop the focus mechanism — fixed rigid tube
    Per review, the printed focus threading (helicoid) was unlikely to work well and
    added a moving joint in the load path. Simplified to one rigid tube:
    - `flange` merges back into `stem` (body interface + 808 nm filter cell + a short
    Ø28 neck). Removed `flange.scad`, `clamp.scad`, `helix.scad`.
    - `barrel` is now most of the length (Ø90 x ~132 mm) with a socket in its rear;
    the stem neck plugs `join_len` in and is pinned by 3 radial M3 screws into a
    groove. The barrel carries the light cone (still ~Ø45 sixty mm behind the optic)
    until it has shrunk to ~Ø18, where the narrow neck takes over — `neck_bore` is
    derived from `co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
    [receiver.scad, vibrometer_80mm.scad]
2026-09-06 receiver: filter cell for the real Ø8.0 x 0.55 mm filter
    Datasheet: 808 nm narrow BP, circular Ø8.0 x 0.55 mm glass, CWL 808+/-2, HBW 25 nm.
    - filter_thk 1.2 (guess) -> 0.55 (spec). filter_fit 0.25 -> 0.30.
    - A 0.55 mm filter can't be clamped by a flat ring bottoming on a shoulder, so the
    filter cell is rebuilt: the filter drops into a Ø8.6 pocket and seats on the Ø6
    field-stop shoulder; `filter_ring` becomes a TOP HAT whose Ø8.1 nose reaches
    down through the Ø17 retainer thread onto the filter rim (~2.5 mm engagement,
    zero-load retainer). Fixes the solid-plug bug where there was no through hole.
    - The cell now lives in a dedicated Ø24 boss (`filter_boss_d`) on the body side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
    [vibrometer_80mm.scad]
2026-09-06 receiver: make the filter_ring actually screwable
    Checked the assembly sequence: with the old fring_nose_h = 3.0 the nose bottomed
    on the filter before the ring's body shoulder reached the stem shoulder, leaving
    only ~2.5 mm engagement and no clean stop.
    - fring_nose_h 3.0 -> 2.0 = exactly the Ø8.6-pocket-to-filter gap, so the nose
    contact and the body-shoulder-on-Ø17->Ø8.6-step happen simultaneously: full
    3.5 mm thread engagement, zero clamp stress on the 0.55 mm glass, ~2.3 turns of
    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
2026-09-06 receiver: fix the filter_ring bore so it can actually screw in
    Real bug: the Ø8.6 filter pocket ran all the way out the boss top, so the ring's
    Ø17 threaded body would jam against the Ø8.6 wall ~3.5 mm short of seated — you
    could not screw it home.
    Stem bore above the seat is now stepped: Ø8.6 pocket -> funnel -> Ø17 thread
    (3.5 mm) -> Ø17.6 clearance -> boss top. The ring body drops through the Ø17.6
    clearance, threads down, and seats with the nose on the filter exactly as the
    body shoulder bottoms on the Ø17->Ø8.6 step. filter_ring body_h +1.5 so its
    slotted head clears the boss top.
    stem / filter_ring 2-manifold; `make check` green.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
2026-09-06 base: make the wall bracket take a real 1/4"-20 heat-set insert
    The `base` part named a 1/4"-20 insert but cut a Ø8×10 pocket into a 5 mm
    plate: the pocket punched clean through and out the top face, leaving a
    through-hole with no floor and no seat. Only ~5 mm of a ~10 mm insert would
    have been surrounded by plastic, and it would have protruded past the
    mounting face so the bracket couldn't sit flat.
    - Add a central boss on the camera-side (+Z) face, tall enough to bury the
    insert with a 3 mm floor behind it. Boss height is derived from
    INSERT_1420_H so it self-adjusts.
    - Blind Ø8 pocket, mouth at the boss top, pressed in from +Z (the fixing
    screws countersink into this same face,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
2026-09-07 receiver: thread into a stock C-mount instead of a custom front plate
    The vibrometer receiver's `stem` was a bespoke front plate — a verbatim copy
    of the camera register + 4-corner M3 pattern, bolted to a bare body. Add a
    `mount` param so it can instead screw straight into a stock generic_29mm_c
    front plate like any C-mount lens, with no custom plate to keep in sync.
    - mount = "C" (default): stem ends in a male 1"-32 thread + Ø34 grip shoulder
    (stem_cmount()). The filter cell is shrunk (fring_d 11.5, cell Ø ~15,
    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
    [receiver.scad, vibrometer_80mm.scad]
2026-09-07 receiver: fix stem_cmount chamfers slicing the part into 3 shells
    The two chamfer cuts in stem_cmount() subtracted solid cones coaxial with
    the part, so instead of breaking an outer edge they removed the entire
    cross-section over their z-range and severed the central column:
    - the shoulder edge chamfer (d1 = shoulder_d + 1) cut the neck off the
    shoulder disc -> neck z < -3 became a free-floating shell
    - the thread lead-in chamfer (d1 = cmount_male_d + 0.6, d2 = 22.6) cut the
    Ø15 filter boss off the male thread -> boss tip z > 6.2 became a free
    shell
    The stem STL came out as 3 disconnected watertight pieces. make check
    (echo only) and CGAL "Simple: yes" (per-shell) both missed it.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
2026-09-07 receiver: move the filter cell -Z of the seating plane (nothing into the camera)
    The C-mount filter cell projected a Ø15 tube ~10 mm past the flange, through the
    front plate's Ø16 bore and into the body cavity. That relied on a specific stock
    front plate being clear and broke the body-modularity contract (a variant with a
    filter drawer / IR-cut holder / thick plate behind the mount would collide), and
    it made the receiver a poor C-mount citizen on non-mapscam cameras.
    The filter is only 0.55 mm and the neck has ~30 mm of unused length, so the whole
    cell now sits on the -Z (target/barrel) side of the seating plane, cut into the
    neck root:
    +Z: [ Ø12 clear bore through the bare thread ]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
2026-09-07 body: NATO accessory rail on the -Y face
    The enclosure had no attachment point on the body itself — the only tripod
    thread is on the rear-cap edge, well behind the centre of mass. Add a
    NATO-style dovetail down the body's -Y face so the load path goes into the
    main box section and a clamp can slide to the balance point.
    - new scad/lib/camera/accessory_rail.scad: nato_section() profile,
    nato_rail() (additive, smooth 45 deg dovetail + integral front dam),
    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
2026-09-07 accessory_rail: drop the front dam, put rails on any face
    - No integral dam. Both rail ends open; the clamp is retained by jaw friction
    plus a stop screw in an end crown hole (nato_hole_zs now anchors a hole at
    each end, fills the middle at <= acc_rail_pitch).
    - acc_rails() / acc_rail_pockets() dispatch a rail onto any of "-Y" "+Y"
    "-X" "+X" via acc_rail_faces (list). Default ["-Y"]. -X/+X use outer_x/2,
    ±Y use outer_y/2, so non-square bodies place correctly.
    - acc_rail_holes already gates the crown inserts; keep it.
    make check green; body renders 2-manifold with 0..4 rails, holes on/off.
2026-09-07 accessory_rail: use the Picatinny/STANAG clamp profile
    The camera "NATO rail" has no published drawing of its own — it's the
    Picatinny / STANAG 4694 clamping geometry run smooth and low. The eyeballed
    10→14 mm mushroom was ~7 mm too narrow for any real clamp to grip.
    - nato_section() is now a Picatinny-family hex top: web → 45° out to
    NATO_W_MAX (21.2 mm, the 0.835" clamp-chamfer width) → 45° in to the
    NATO_W_TOP flat (15.7 mm). Small NATO_TIP land at the widest point.
    - NATO_H falls out of the widths at 45° (~5.6 mm) — MIL-STD-1913 fixes no
    height, so it stays low-profile.
    - Crown M3 pockets now bottom a mm or two into the host wall (rail is
    shallower than a 5 mm inser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
2026-09-07 renders: regenerate camera previews with the accessory rail
    make doesn't rebuild the preview PNGs on a lib-only change; refresh them so
    the committed previews show the -Y NATO rail. (CS body length still reflects
    the separate variant-override bug — tracked elsewhere.)
2026-09-07 fix: variant TOML overrides never reached the geometry
    Generated variant stubs do `include params -> re-assign the TOML params ->
    include dispatch`, but dispatch.scad pulls part modules with `use <body.scad>`
    and each part file self-includes params.scad. OpenSCAD resolves a used
    module's free variables against its own definition scope, so the parts always
    saw params.scad DEFAULTS, not the stub's overrides.
    `params.scad`'s echo() runs in the stub scope and printed the right numbers,
    which masked it. `-D` on the CLI is applied globally and does reach used
    modules. `make check` only passed `-D part=...`, so it never caught this.
    Impact:
    - generic_29mm_cs body rendered at the C-mount length (2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
2026-09-23 receiver: thread the lens retainer instead of set screws
    The Ø80 optic's pocket was walled in on both ends — the front aperture
    and the rear trunk bore were each narrower than the element — so it had
    no physical path into its own seat ("thin ridge" blocking assembly).
    Ports the threaded-retainer scheme already used by the `lens` component
    (scad/lib/lens/retainer.scad): the optic now loads from the front
    (muzzle) end through a bore that stays wider than element_d all the way
    to its seat shoulder, and lens_retainer becomes an externally-threaded
    ring that screws into a matching internal thread in the barrel and
    clamps the optic back onto the seat. Replaces the 3 radial M3 set
    screws + V-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
2026-09-23 threads: printable-thread rules + print_thread() helper
    The vibrometer barrel's Ø84.6 lens-retainer thread printed badly: male and
    female were both modelled at d = 84.6 with BOSL2's default $slop = 0 (zero
    clearance), used a 60° ISO profile (60° flank overhangs axis-vertical), $fn = 64
    (4.2 mm facets at Ø85), and had no bed-face bevel for elephant's foot.
    - docs/printable-threads.md: the rules (axis vertical, pitch >= 1.5, clearance
    0.30 + 0.003·d on the internal half, 45° flanks, >= 3 turns, blunt start +
    bevels, <= 0.4 mm facets, walls sized from the real cut), with sources.
    - scad/lib/threads.scad: print_thread() applies and asserts them; PT_* constants.
    - Receiver lens retaine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
2026-09-23 receiver: hold the barrel's OD->socket taper to <=45 deg
    The barrel prints optic-end-down, so the bore taper down to the stem socket is
    a ceiling overhang. With a fixed 14 mm taper it sat at ~59 deg from vertical.
    taper_len now comes from the radial drop (max(14, (barrel_od - socket_od)/2)),
    so the bore taper is ~40 deg. Adds an assert that the longer taper still clears
    the light cone, and notes the brim needed for the barrel's narrow bed ring.
    Ported from the uncommitted overhang work in the
    vibrometer-lens-printability worktree (front-plate changes not included).
